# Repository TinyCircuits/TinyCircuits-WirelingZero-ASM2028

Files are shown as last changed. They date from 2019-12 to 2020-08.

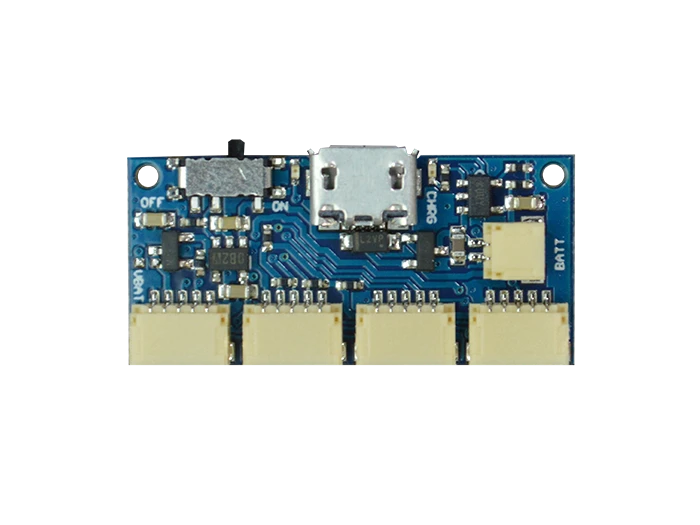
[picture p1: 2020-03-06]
images/ASM2028-Tutorial-Image-00.png

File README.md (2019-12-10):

# TinyCircuits-WirelingZero-ASM2028
# ASM2028 Rev2

The design files are located under design_files/ for the TinyCircuits ASM2028 Rev2 PCB. This is a processor board designed for low-cost Wireling projects. Includes 4 separately addressable Wireling ports.

Format is in Cadsoft Eagle format - Eagle version 6.2 was used for the original design.

For more infomation, check out the product page at TinyCircuits.com

# License:

Design by TinyCircuits.
All design files are released under the Creative Commons Attribution Share-Alike 3.0 License, see the following link for details: http://creativecommons.org/licenses/by-sa/3.0

All text above must be included in any redistribution or derived design

This project uses designs and concepts developed as part of the Arduino project and the LilyPad project.  The TinyCircuits design files themselves (schematics, PCB and libraries) are not directly derived from these works' design files and have been created new, however the concepts and basic architecture behind the TinyDuino and TinyLily products are derived and we thank the hard work of the organizations below for their contributions to open-source hardware:
  
Original Arduino Uno Design by Team Arduino

LilyPad Arduino Design by Leah Buechley and Sparkfun Electronics

Please support the open-source hardware community

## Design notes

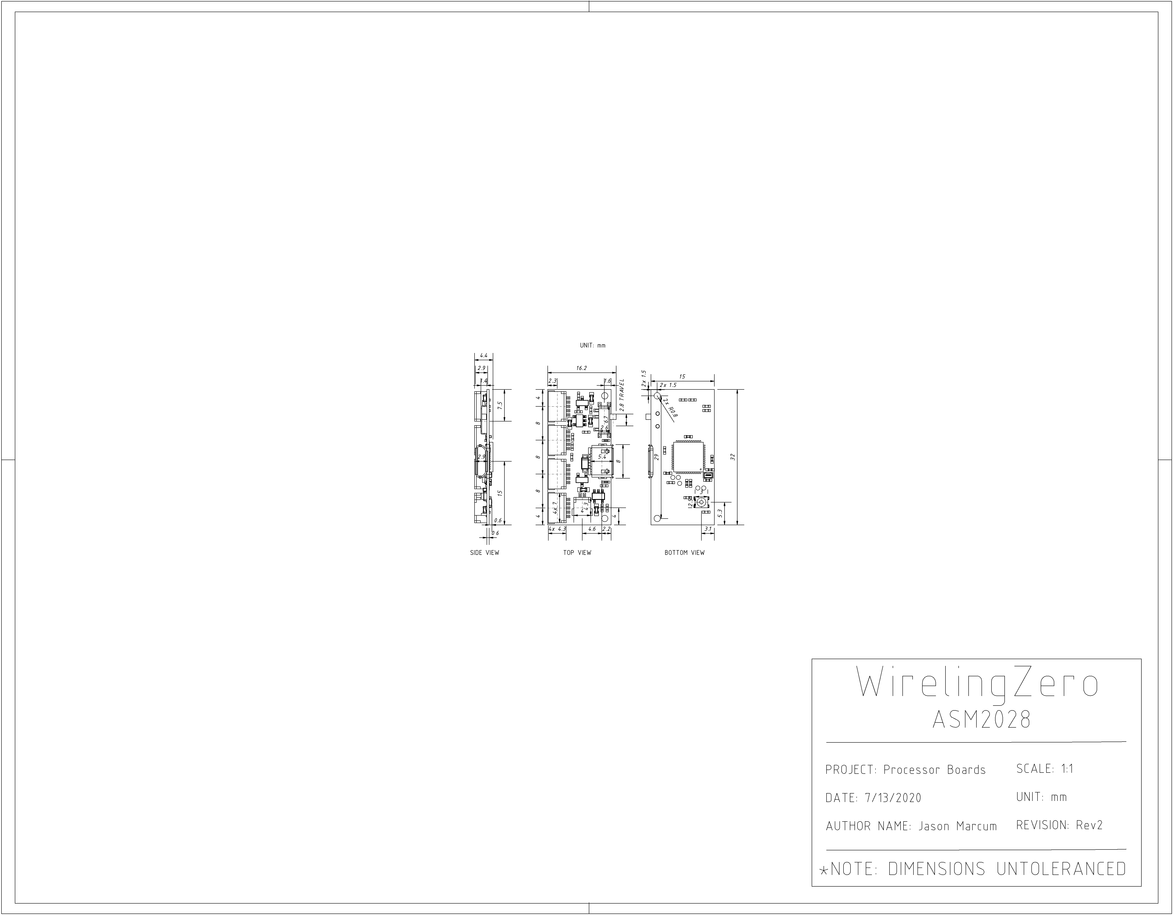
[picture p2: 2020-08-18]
cad/WirelingZero_ASM2028_REV2-DETAILED_DRAWING-PNG.png

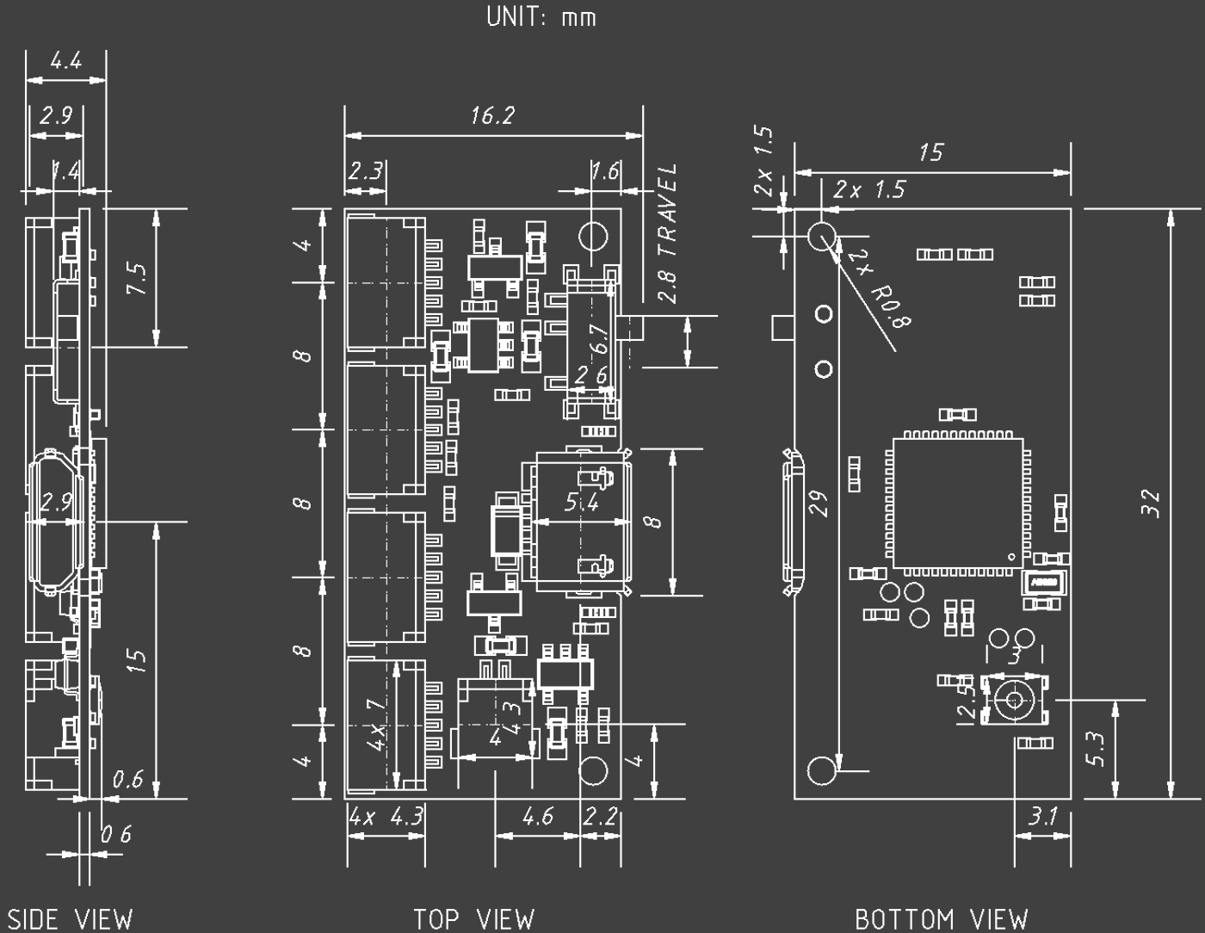
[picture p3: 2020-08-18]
cad/WirelingZero_ASM2028_REV2-DETAILED_DRAWING_COMPACT-PNG.png

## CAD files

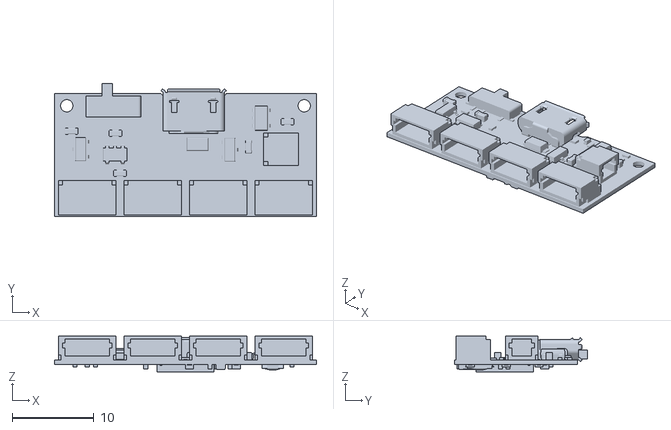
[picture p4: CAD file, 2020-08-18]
cad/WirelingZero_ASM2028_REV2-STL.stl
32.0 x 16.2 x 4.37

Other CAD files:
cad/WirelingZero_ASM2028_REV2-DETAILED_DRAWING-DXF.dxf

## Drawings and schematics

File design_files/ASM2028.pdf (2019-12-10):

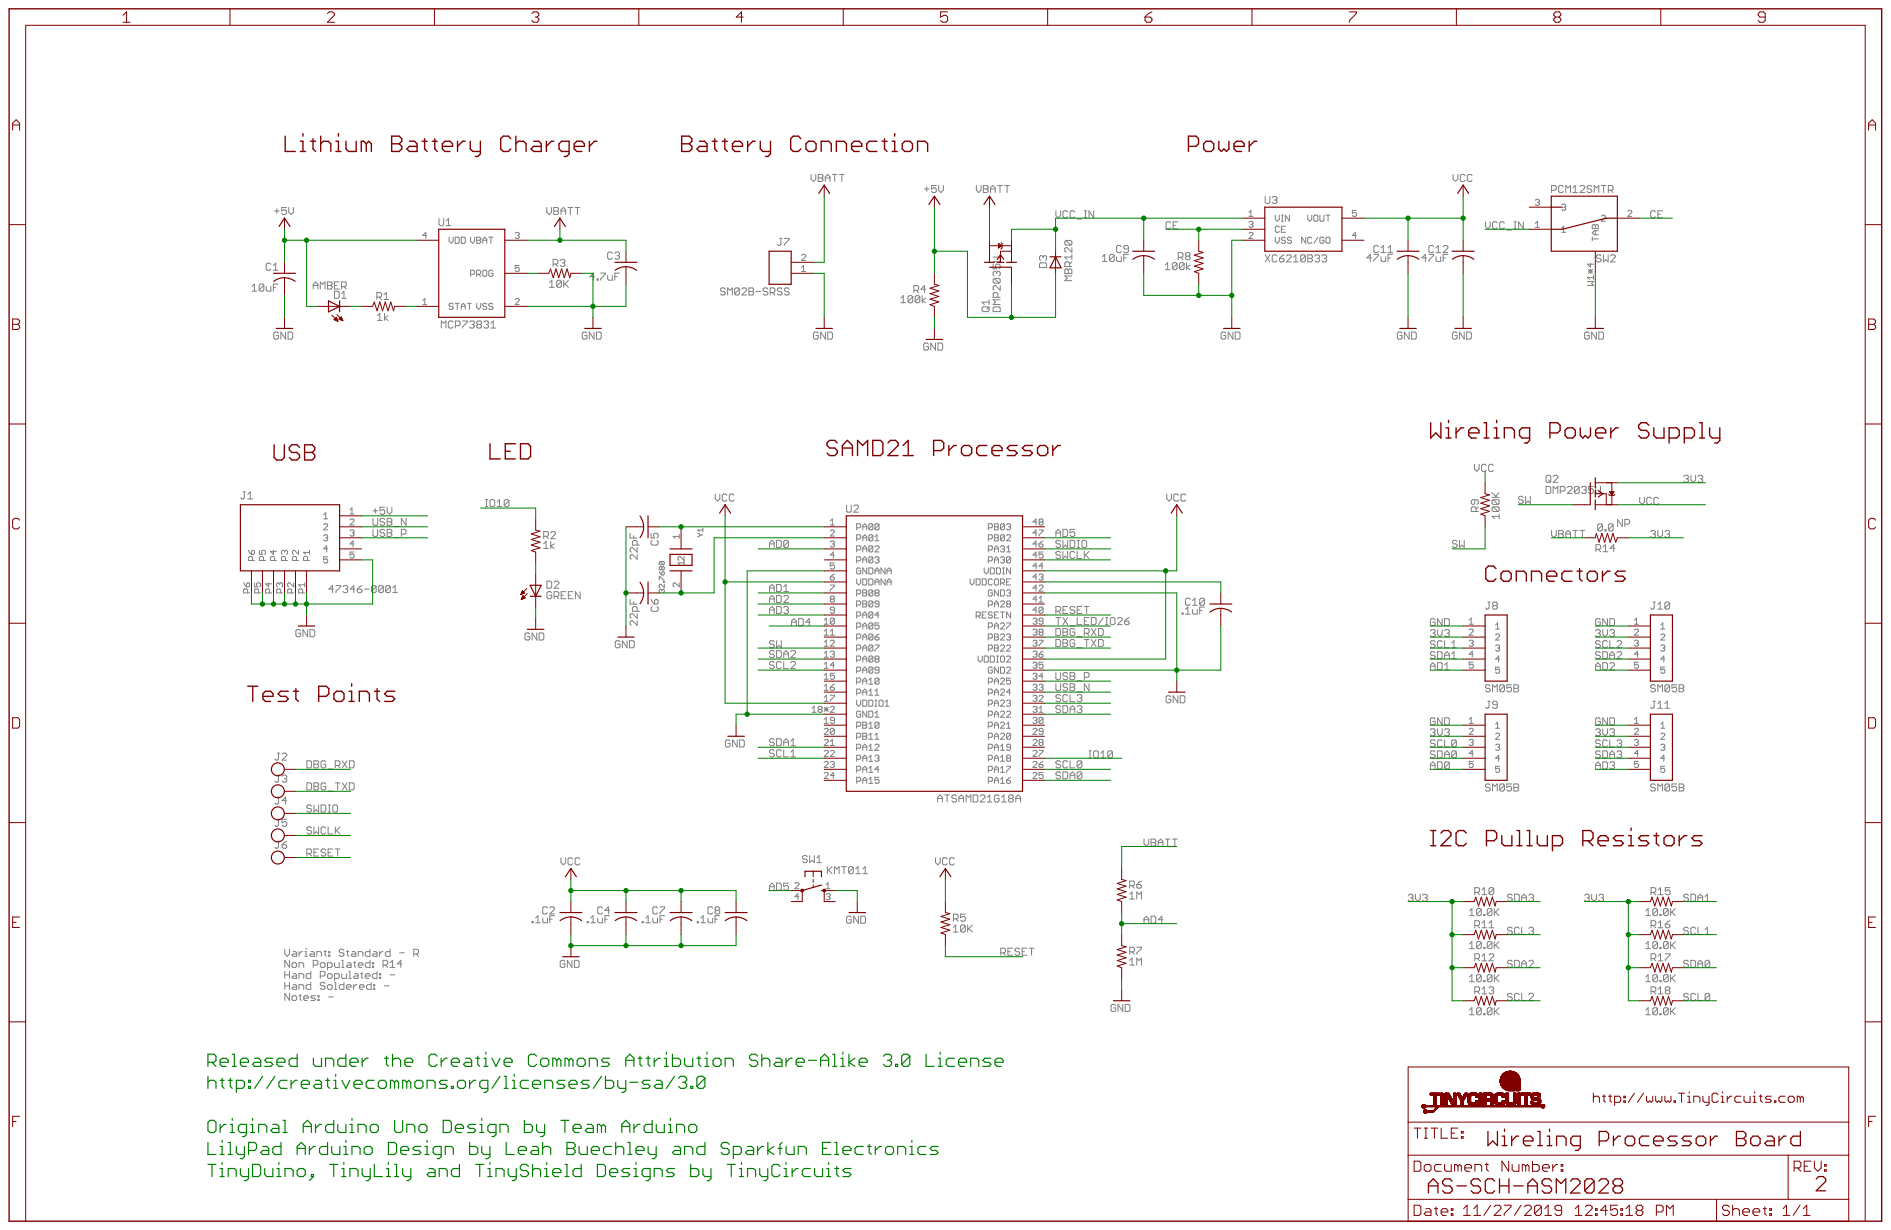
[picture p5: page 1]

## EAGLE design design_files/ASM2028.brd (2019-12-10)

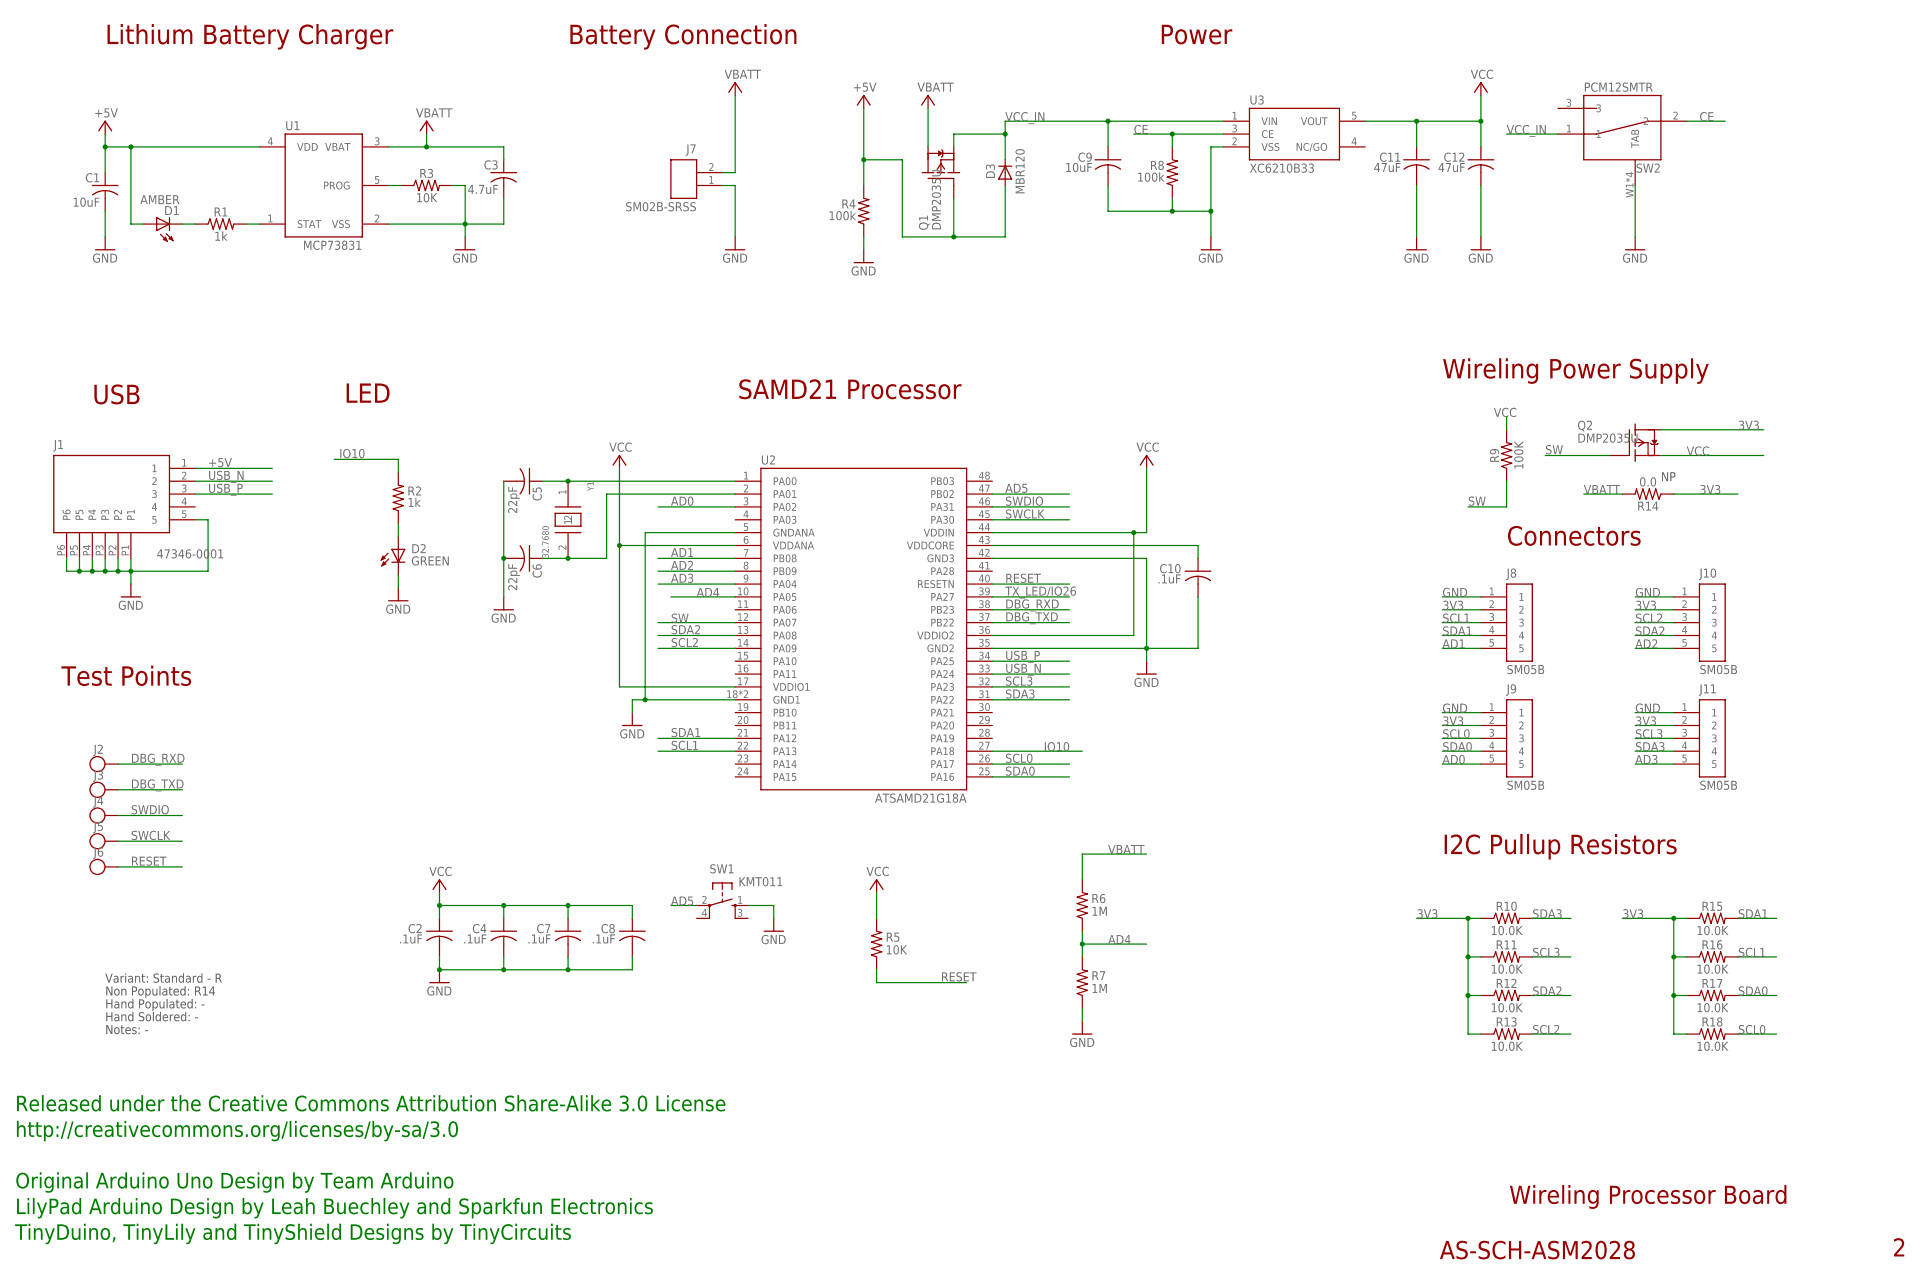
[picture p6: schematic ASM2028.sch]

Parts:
C1, C9: 10uF; C0603; PARTNO AS-ITM-00002
C2, C4, C7, C8, C10: .1uF; C0402; PARTNO AS-ITM-00008
C3: 4.7uF; C0603; PARTNO AS-ITM-00088
C5, C6: 22pF; C0402; PARTNO AS-ITM-00211
C11, C12: 47uF; C0603; PARTNO AS-ITM-00558
D1: AMBER; 0402_LED; PARTNO AS-ITM-00058
D2: GREEN; 0402_LED; PARTNO AS-ITM-00038
D3: MBR120; SOD-123FL
J1: 47346-0001; MICRO_USB
J2, J3, J4, J5, J6: TEST_POINT; TEST_POINT_1MM
J7: SM02B-SRSS; JST_SH_2X1
J8, J9, J10, J11: SM05B; JST_SH_5X1_EDGE
Q1: DMP2035U; SOT23A
Q2: DMP2035U; SOT23A; PARTNO AS-ITM-00024
R1, R2: 1k; 0402; PARTNO AS-ITM-00003
R3: 10K; 0402
R4, R8: 100k; 0402; PARTNO AS-ITM-00004
R5: 10K; 0402; PARTNO AS-ITM-00032
R6, R7: 1M; 0402; PARTNO AS-ITM-00005
R9: 100K; 0402
R10, R11, R12, R13, R15, R16, R17, R18: 10.0K; 0402
R14: 0.0; 0402; PARTNO AS-ITM-00076
SW1: KMT011
SW2: PCM12SMTR
U1: MCP73831; SOT-23
U2: ATSAMD21G18A; QFN48; PARTNO AS-ITM-00273
U3: XC6210B33; SOT-25
Y1: 32.7680; ABS06; PARTNO AS-ITM-00279

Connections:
3V3: J8.2, J9.2, J10.2, J11.2, Q2.C (D), R10.1, R11.1, R12.1, R13.1, R14.1, R15.1, R16.1, R17.1, R18.1
+5V: C1.1, D1.1 (A), D3.A, J1.1, Q1.B (G), R4.2, U1.4 (VDD)
AD0: J9.5, U2.3 (PA02)
AD1: J8.5, U2.7 (PB08)
AD2: J10.5, U2.8 (PB09)
AD3: J11.5, U2.9 (PA04)
AD4: R6.1, R7.2, U2.10 (PA05)
AD5: SW1.2, U2.47 (PB02)
CE: R8.2, SW2.2, U3.3 (CE)
DBG_RXD: J2.P$1, U2.38 (PB23)
DBG_TXD: J3.P$1, U2.37 (PB22)
GND: C1.2, C2.2, C3.2, C4.2, C5.2, C6.2, C7.2, C8.2, C9.2, C10.2, C11.2, C12.2, D2.2 (C), J1.5, J1.P1, J1.P2, J1.P3, J1.P4, J1.P5, J1.P6, J7.1 (2), J8.1, J9.1, J10.1, J11.1, R3.2, R4.1, R7.1, R8.1, SW1.1, SW2.W1 (TAB), SW2.W2 (TAB), SW2.W3 (TAB), SW2.W4 (TAB), U1.2 (VSS), U2.5 (GNDANA), U2.18 (GND1), U2.35 (GND2), U2.42 (GND3), U2.EXP (GND1), U3.2 (VSS)
IO10: R2.2, U2.27 (PA18)
unnamed: C5.1, U2.1 (PA00), Y1.1
unnamed: C6.1, U2.2 (PA01), Y1.2
unnamed: D2.1 (A), R2.1
unnamed: D1.2 (C), R1.1
unnamed: R3.1, U1.5 (PROG)
unnamed: R1.2, U1.1 (STAT)
unnamed: C10.1, U2.43 (VDDCORE)
RESET: J6.P$1, R5.1, U2.40 (RESETN)
SCL0: J9.3, R18.2, U2.26 (PA17)
SCL1: J8.3, R16.2, U2.22 (PA13)
SCL2: J10.3, R13.2, U2.14 (PA09)
SCL3: J11.3, R11.2, U2.32 (PA23)
SDA0: J9.4, R17.2, U2.25 (PA16)
SDA1: J8.4, R15.2, U2.21 (PA12)
SDA2: J10.4, R12.2, U2.13 (PA08)
SDA3: J11.4, R10.2, U2.31 (PA22)
SW: Q2.B (G), R9.1, U2.12 (PA07)
SWCLK: J5.P$1, U2.45 (PA30)
SWDIO: J4.P$1, U2.46 (PA31)
TX_LED/IO26: U2.39 (PA27)
USB_N: J1.2, U2.33 (PA24)
USB_P: J1.3, U2.34 (PA25)
VBATT: C3.1, J7.2 (1), Q1.C (D), R6.2, R14.2, U1.3 (VBAT)
VCC: C2.1, C4.1, C7.1, C8.1, C11.1, C12.1, Q2.E (S), R5.2, R9.2, U2.6 (VDDANA), U2.17 (VDDIO1), U2.36 (VDDIO2), U2.44 (VDDIN), U3.5 (VOUT)
VCC_IN: C9.1, D3.C, Q1.E (S), SW2.1, U3.1 (VIN)

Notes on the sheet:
SAMD21 Processor
Power
LED
Wireling Processor Board
AS-SCH-ASM2028
Released under the Creative Commons Attribution Share-Alike 3.0 License
http://creativecommons.org/licenses/by-sa/3.0
Original Arduino Uno Design by Team Arduino
TinyDuino, TinyLily and TinyShield Designs by TinyCircuits
LilyPad Arduino Design by Leah Buechley and Sparkfun Electronics
Lithium Battery Charger
Battery Connection
USB
Test Points
Non Populated: R14
Hand Populated: -
Hand Soldered: -
Notes: -
Variant: Standard - R
Wireling Power Supply
Connectors
I2C Pullup Resistors

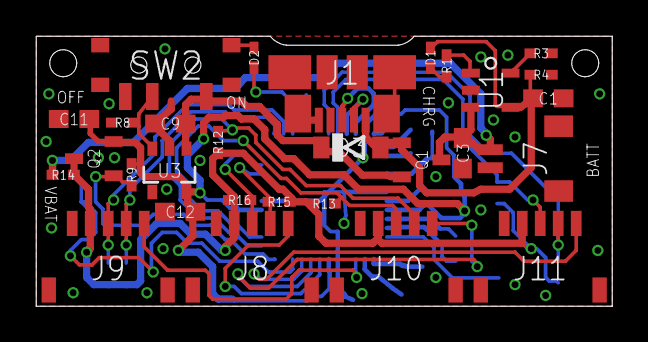
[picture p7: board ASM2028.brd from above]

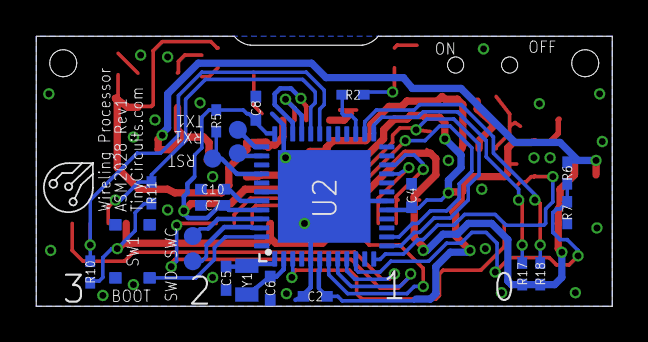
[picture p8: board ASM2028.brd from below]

Board: 2 copper layers, 32.0 x 15.0 mm, 53 parts (23 on the bottom side), 37 nets.

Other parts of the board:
U$1: DOCFIELD-TINYCIRCUITS-PCB

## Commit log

2020-06-26 Add CAD data
2020-06-29 Rename files, add dxf, and use new 2D drawing template
    [WirelingZero_ASM2028_DXF_REV2.dxf]
2020-07-01 Remove vias in models & drawings, add compact dimension image, and remove a file to reduce size
    [WirelingZero_ASM2028_DXF_REV2.dxf, WirelingZero_DXF_ASM2028_REV2.dxf, WirelingZero_STL_ASM2028_REV2.stl]
2020-07-02 Add zip of all CAD files
2020-08-18 Update CAD drawings
    [WirelingZero_ASM2028_REV2-DETAILED_DRAWING-DXF.dxf, WirelingZero_ASM2028_REV2-STL.stl, WirelingZero_DXF_ASM2028_REV2.dxf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]
